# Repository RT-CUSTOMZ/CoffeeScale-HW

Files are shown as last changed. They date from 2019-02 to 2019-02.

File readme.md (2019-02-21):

# HX711 Board

* RATE Pin connected to GND -> 10 Hz mode
* X1 Pin connected to GND -> on-chip oscillator is activate

## InteractiveHtmlBom

[Link to interactive bom](https://htmlpreview.github.io/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)

## Schematics

[Link to Schematic pdf](./coffee-scale.pdf )

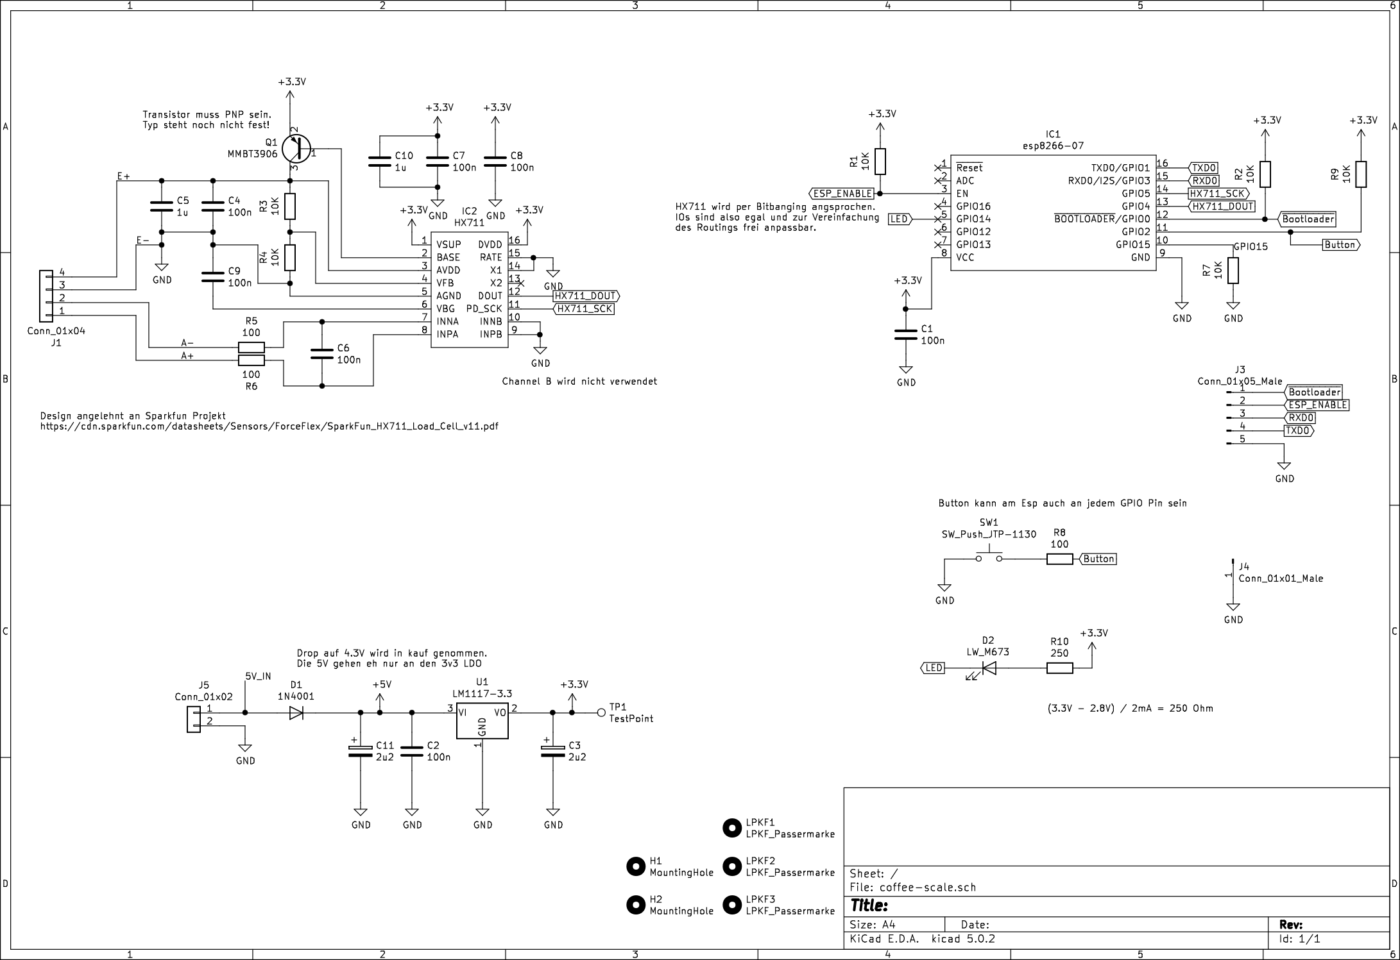
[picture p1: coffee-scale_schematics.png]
Schematics


## Messbrücke

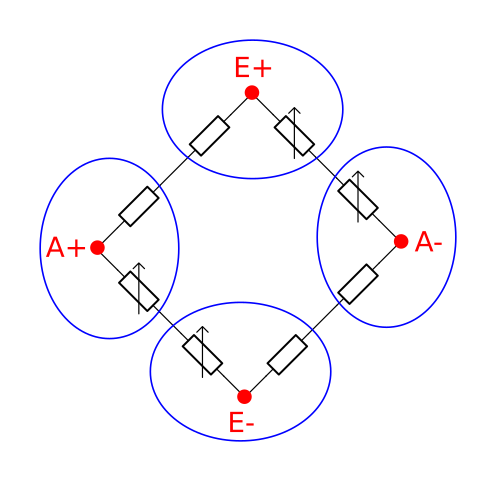
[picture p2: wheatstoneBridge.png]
Wheatstone Brdge


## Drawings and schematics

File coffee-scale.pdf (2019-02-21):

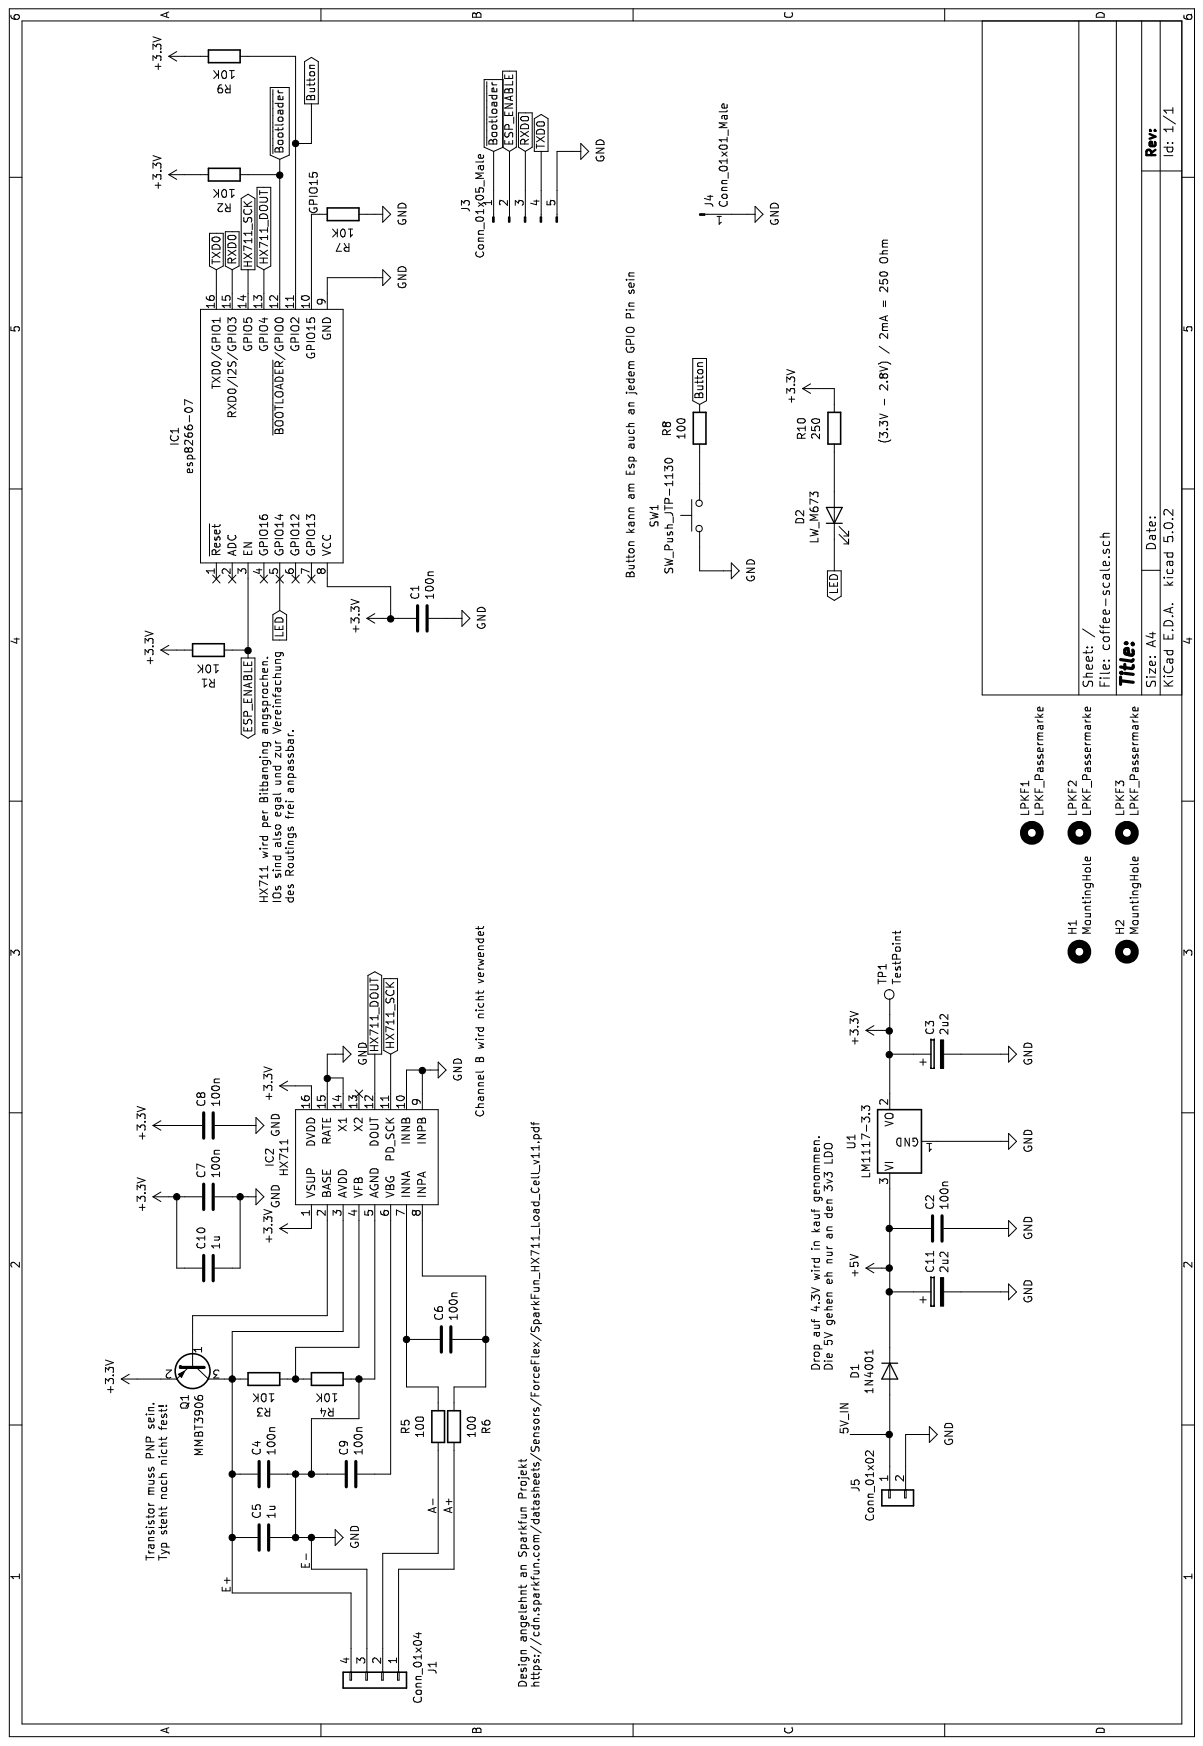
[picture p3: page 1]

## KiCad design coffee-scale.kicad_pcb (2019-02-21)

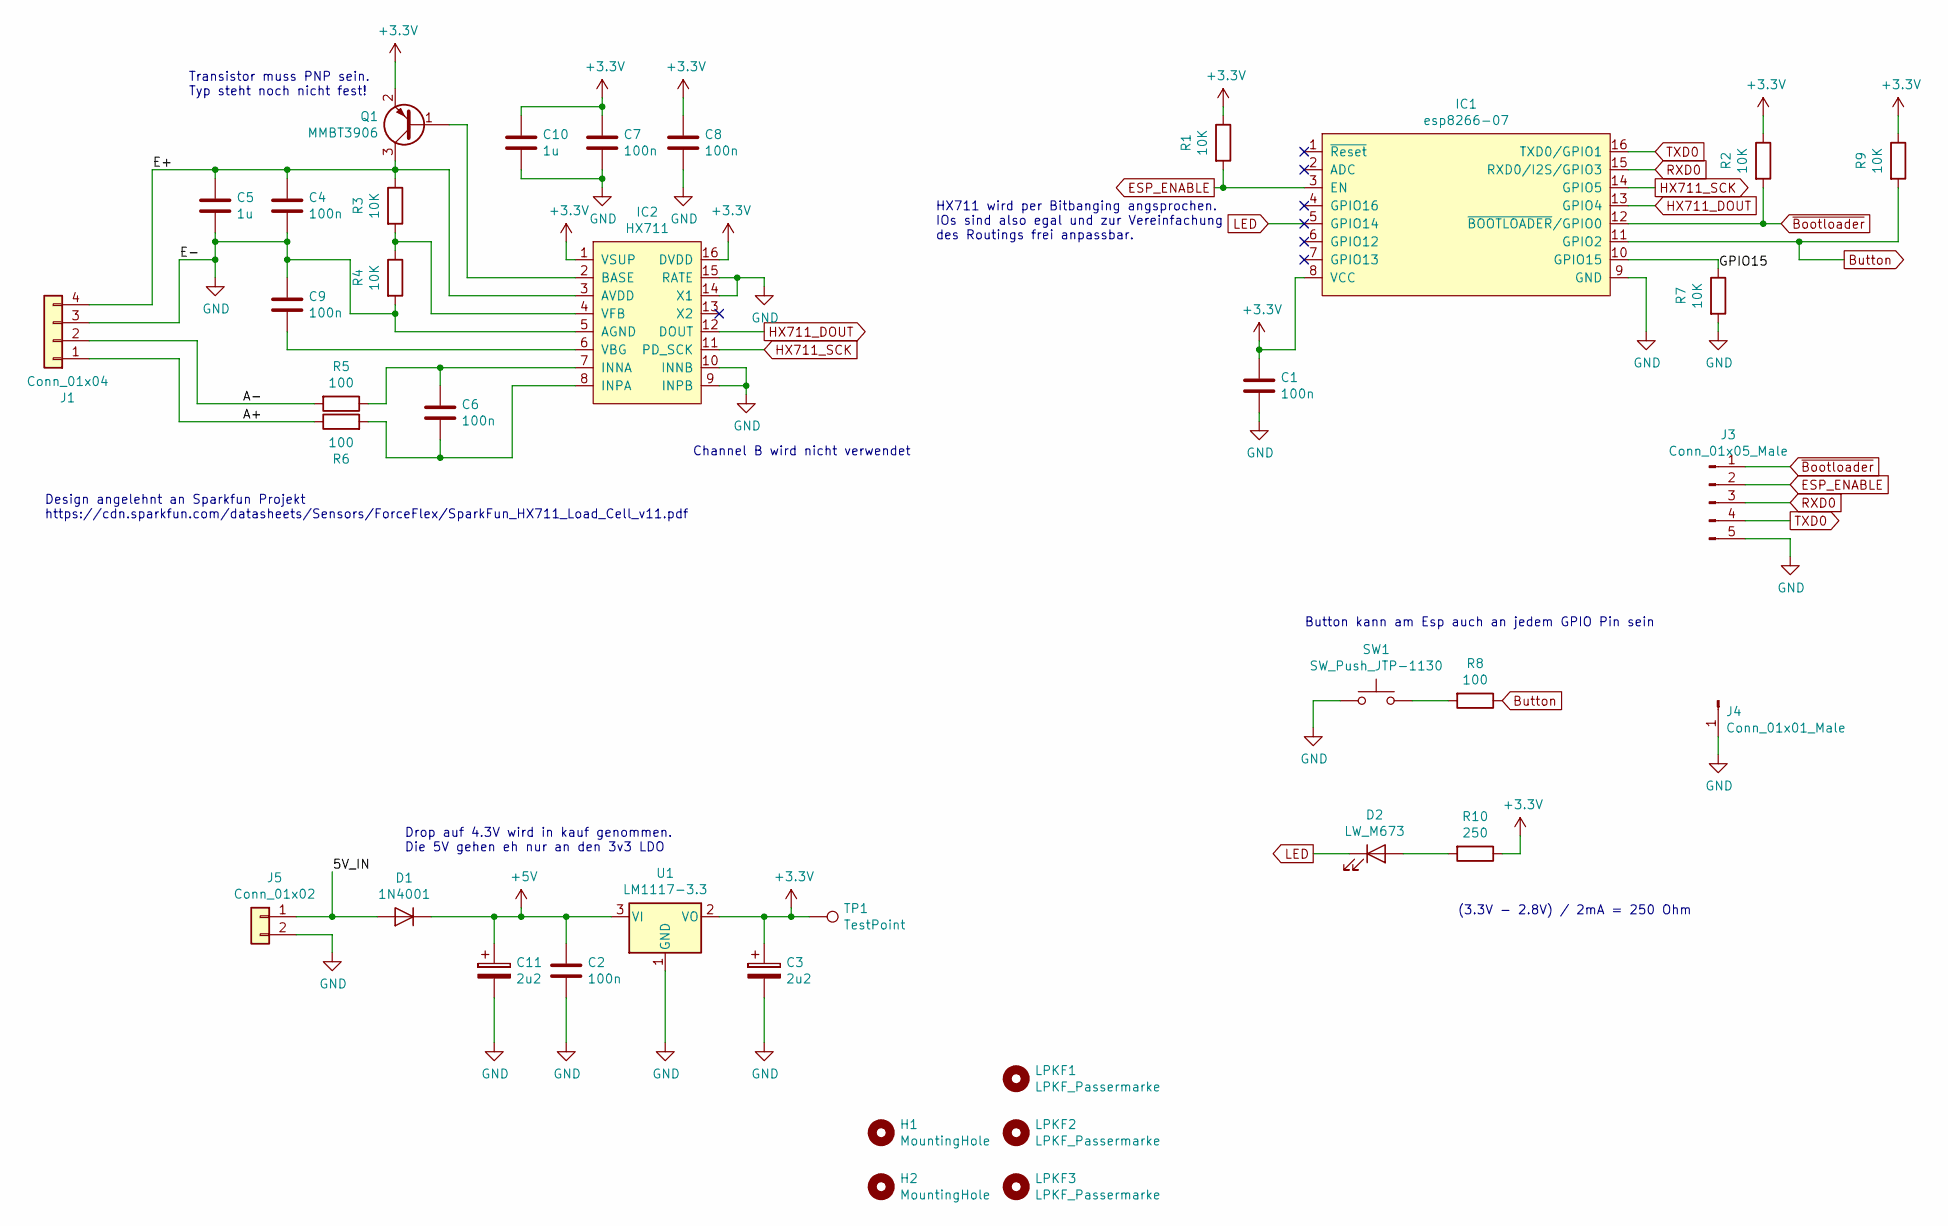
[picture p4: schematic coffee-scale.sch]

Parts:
C1, C2, C4, C6, C7, C8, C9: 100n; C_0805_2012Metric_Pad1.15x1.40mm_HandSolder
C3, C11: 2u2; CP_Elec_4x5.4
C5, C10: 1u; C_0805_2012Metric_Pad1.15x1.40mm_HandSolder
D1: 1N4001; D_MELF_Handsoldering
D2: LW_M673
H1, H2: MountingHole; MountingHole_5.5mm
IC1: esp8266-07; ESP-07_smd
IC2: HX711; SOP-16_4.4x10.4mm_P1.27mm
J1: Conn_01x04; PinHeader_1x04_P2.54mm_Horizontal
J3: Conn_01x05_Male; PinHeader_1x05_P2.54mm_Vertical
J4: Conn_01x01_Male; SolderWirePad_1x01_Drill1.2mm
J5: Conn_01x02; PinHeader_1x02_P2.54mm_Horizontal
LPKF1, LPKF2, LPKF3: LPKF_Passermarke; LPKF_Passermarke_Pad_D1.5mm
Q1: MMBT3906; SOT-23
R1, R2, R3, R4, R7, R9: 10K; R_0805_2012Metric_Pad1.15x1.40mm_HandSolder
R5, R6, R8: 100; R_0805_2012Metric_Pad1.15x1.40mm_HandSolder
R10: 250; R_0805_2012Metric_Pad1.15x1.40mm_HandSolder
SW1: SW_Push_JTP-1130; SW_SPST_JTP-1130
TP1: TestPoint; TestPoint_THTPad_D2.0mm_Drill1.0mm
U1: LM1117-3.3; SOT-223-3_TabPin2

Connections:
+3V3: C1.1, C3.1, C7.1, C8.1, C10.1, IC1.8 (VCC), IC2.1 (VSUP), IC2.16 (DVDD), Q1.2 (E), R1.1, R2.1, R9.1, R10.1, TP1.1, U1.2 (VO)
+5V: C2.1, C11.1, D1.1 (K), U1.3 (VI)
/5V_IN: D1.2 (A), J5.1
/A+: J1.1, R6.1
/A-: J1.2, R5.2
/E+: C4.1, C5.1, IC2.3 (AVDD), J1.4, Q1.3 (C), R3.1
/GPIO15: IC1.10 (GPIO15), R7.1
Button: IC1.11 (GPIO2), R8.1, R9.2
ESP_ENABLE: IC1.3 (EN), J3.2, R1.2
GND: C1.2, C2.2, C3.2, C4.2, C5.2, C7.2, C8.2, C9.1, C10.2, C11.2, IC1.9 (GND), IC2.5 (AGND), IC2.9 (INPB), IC2.10 (INNB), IC2.14 (X1), IC2.15 (RATE), J1.3, J3.5, J4.1, J5.2, R4.2, R7.2, SW1.1, U1.1 (GND)
HX711_DOUT: IC1.13 (GPIO4), IC2.12 (DOUT)
HX711_SCK: IC1.14 (GPIO5), IC2.11 (PD_SCK)
LED: D2.1 (K), IC1.5 (GPIO14)
unnamed: C6.1, IC2.7 (INNA), R5.1
unnamed: C6.2, IC2.8 (INPA), R6.2
unnamed: C9.2, IC2.6 (VBG)
unnamed: D2.2 (A), R10.2
unnamed: IC2.2 (BASE), Q1.1 (B)
unnamed: IC2.4 (VFB), R3.2, R4.1
unnamed: R8.2, SW1.2
RXD0: IC1.15 (RXD0/I2S/GPIO3), J3.3
TXD0: IC1.16 (TXD0/GPIO1), J3.4
~Bootloader: IC1.12 (~BOOTLOADER~/GPIO0), J3.1, R2.2

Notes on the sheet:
Transistor muss PNP sein. Typ steht noch nicht fest!
Channel B wird nicht verwendet
Design angelehnt an Sparkfun Projekt https://cdn.sparkfun.com/datasheets/Sensors/ForceFlex/SparkFun_HX711_Load_Cell_v11.pdf
HX711 wird per Bitbanging angsprochen. IOs sind also egal und zur Vereinfachung des Routings frei anpassbar.
Drop auf 4.3V wird in kauf genommen. Die 5V gehen eh nur an den 3v3 LDO
Button kann am Esp auch an jedem GPIO Pin sein
(3.3V - 2.8V) / 2mA = 250 Ohm

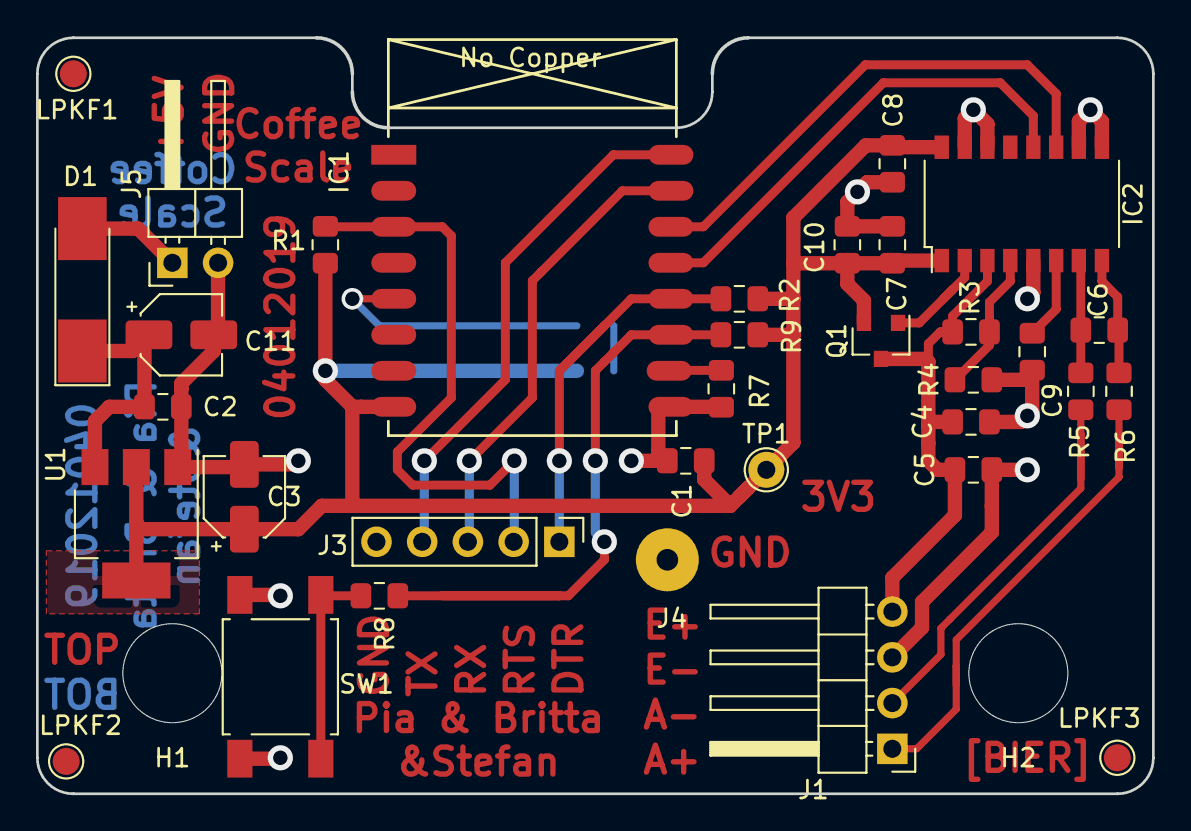
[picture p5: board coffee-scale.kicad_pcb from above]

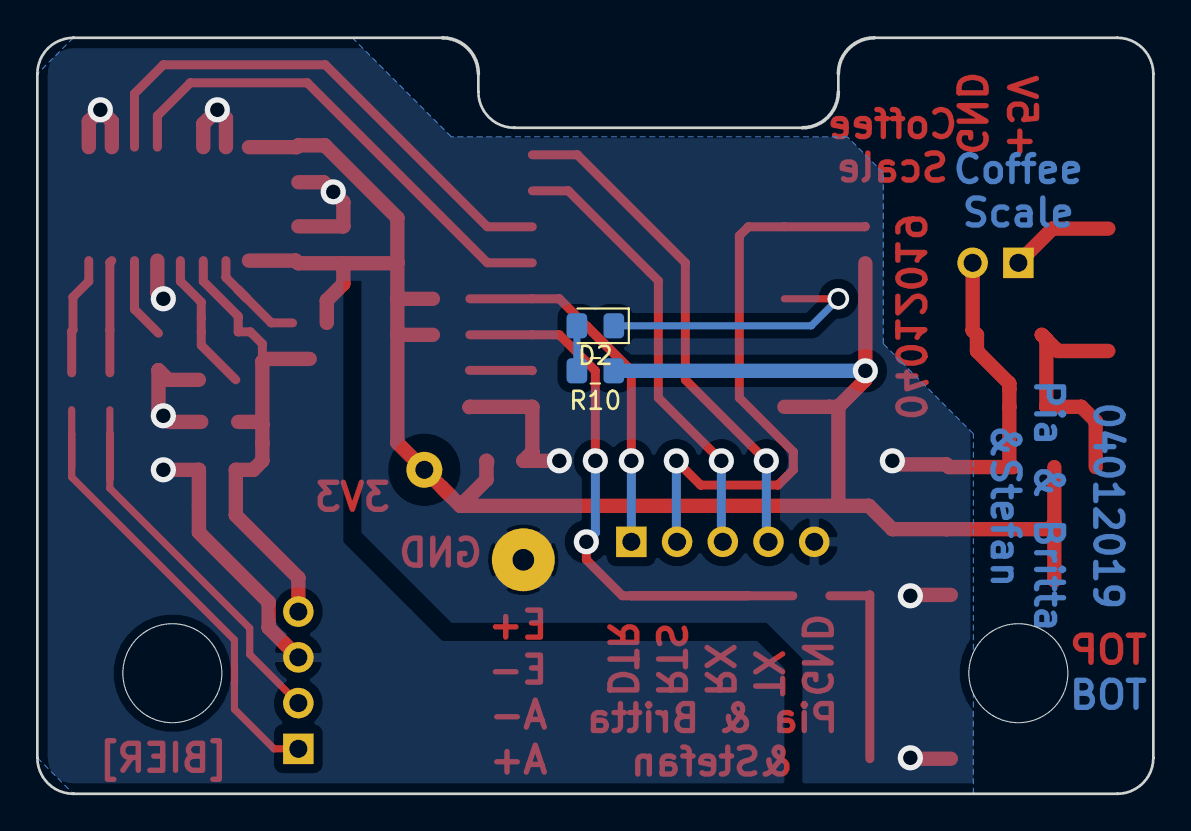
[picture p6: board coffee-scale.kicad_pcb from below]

Board: 2 copper layers, 62.0 x 42.0 mm, 38 parts (2 on the bottom side), 23 nets.

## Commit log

2019-01-05 next pcb version
    fix esp position
    add descriptions to copper
    fix hole positions
    [coffee-scale.kicad_pcb, coffee-scale.sch]
2019-02-21 add interactivehtmlbom
    [coffee-scale.kicad_pcb]
2019-02-21 Update readme.md
    add link to interactive html bom
